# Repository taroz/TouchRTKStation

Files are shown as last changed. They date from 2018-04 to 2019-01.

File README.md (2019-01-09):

# TouchRTKStation
日本語で説明は[**こちら**](https://qiita.com/taroz/items/fe5373848153430bf19d)

## Introduction
- TouchRTKStation is an open-source single-frequency RTK-GNSS rover and base station project
- Single frequency GNSS antenna/receiver+ Raspberry Pi + Touchscreen + RTKLIB + Case
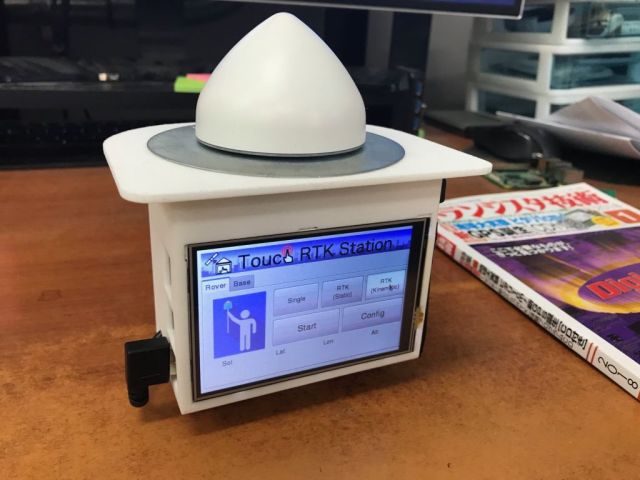
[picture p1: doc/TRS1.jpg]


## Functions
### Rover station
- GNSS raw data and RTK-GNSS solutions can be stored in USB memory
- Single point positioning, Kinematic RTK-GNSS, and Static RTK-GNSS are supported

### Base station
- GNSS raw data can be stored in USB memory
- TCP server, Ntrip Server, and Ntrip caster functions can be used to transmit GNSS data to a rover station
- Wireless communication devices such as ZigBee can be used

## Features
- Using [RTKLIB](https://github.com/tomojitakasu/RTKLIB) for processing GNSS data
- This project is inspired by [RTKLIB_Touchscreen_GUI](https://github.com/Francklin2/RTKLIB_Touchscreen_GUI)
- To compared with [RTKLIB_Touchscreen_GUI](https://github.com/Francklin2/RTKLIB_Touchscreen_GUI)
  - More smaller (5 inch => 4 inch)
  - Simple implementation using RTKLIB applications (rtkrcv and str2str)
  - GUI is developed by PyQT and easily customizable

## How to assemble
### Parts
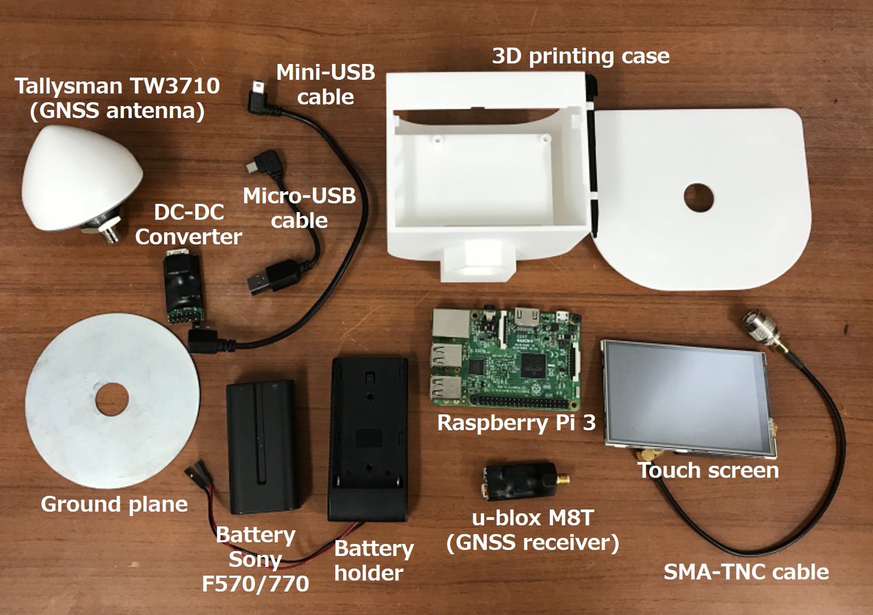
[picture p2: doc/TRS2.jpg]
<p>

- **Case:**  Create using 3D printer (STL data is [here](https://github.com/taroz/TouchRTKStation/blob/master/3D))
  - Or buy from [Shapeways](https://www.shapeways.com/shops/tarosuzuki)
- **GNSS receiver:** u-blox M8T [CSG shop](http://www.csgshop.com/product.php?id_product=205)
- **Mini-USB cable:**
- **GNSS antenna:** Tallysman TW3710 or TW3740 (GPS+GLO+BDS L1) [Digi-Key(TW3710)](https://www.digikey.com/products/en?keywords=tw3710) or  [Digi-Key(TW3710)](https://www.digikey.com/products/en?keywords=tw3740)  
- **Raspberry Pi 3:**
- **micro SD card:**
- **TNC(P)-SMA(J) connector:**
- **SMA(P)-SMA(P) cable:**
- **4inch Display:** Waveshare 4inch_RPi_LCD [Waveshare](https://www.waveshare.com/4inch-rpi-lcd-a.htm)
- **DC-DC converter:** 7.4V to 5V [Strawberry Linux](https://strawberry-linux.com/catalog/items?code=18697), [Amazon](https://www.amazon.com/DZS-Elec-Converter-Regulator-Charging/dp/B07121W7Q4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)
- **micro-USB cable:**
- **Battery holder:** Lilliput Battery Plate for Sony Battery F-970 [eBay](https://www.ebay.com/itm/LILLIPUT-Battery-Adapter-Base-Plate-F970-for-Sony-VX2100E-HVR-V1C-F330-/371421670220), [Amazon](https://www.amazon.com/Battery-Adapter-VX2100E-Lilliput-Accessory/dp/B009SJIG0K)
- **Battery:** Sony NP-F550/F570 (2900mAh) or NP-F750/F770 (5000mAh) [Amazon](https://www.amazon.com/dp/B07DC5RYPM/ref=cm_sw_em_r_mt_dp_U_qOHnCbFWY47XD)
- **5/8 inch nut:**
- **Ground plane:**

## Setup (Hardware)
- Modify the battery holder
- Open and directly connect to the DC-DC converter  
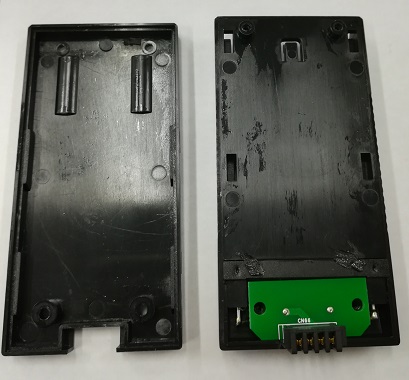
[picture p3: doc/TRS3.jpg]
<p> 
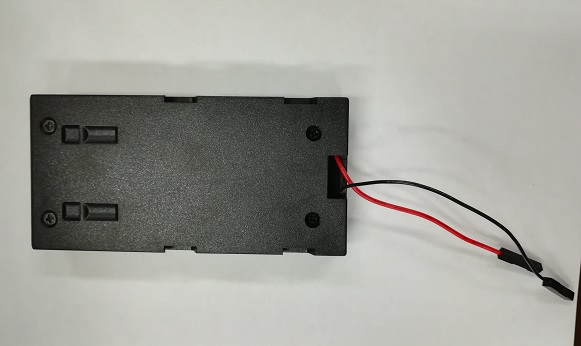
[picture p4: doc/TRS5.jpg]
<p>  

- Mount the battery holder to the main case  
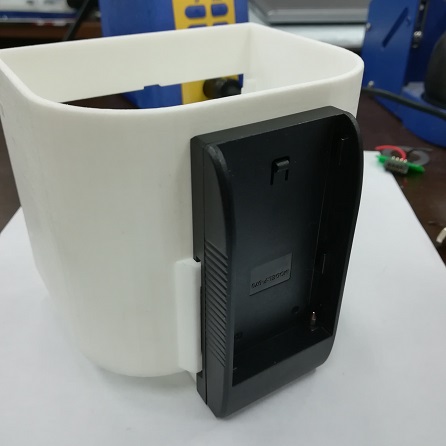
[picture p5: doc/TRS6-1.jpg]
<p>  

- Mount Raspberry Pi to the main case  
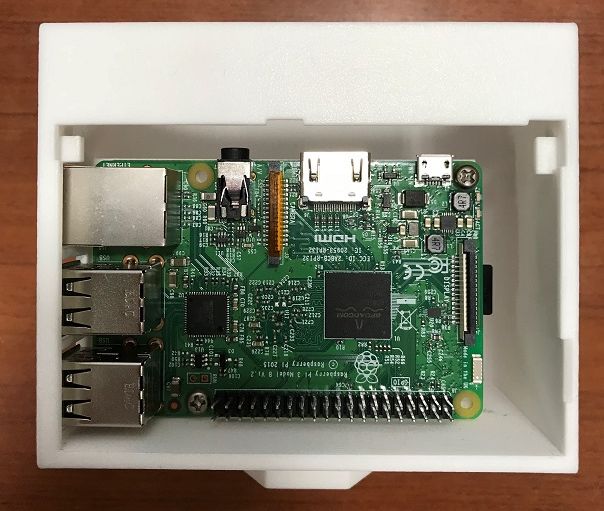
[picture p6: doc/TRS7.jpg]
<p>  

- Mount the Tallysman GNSS antenna to the top plate  
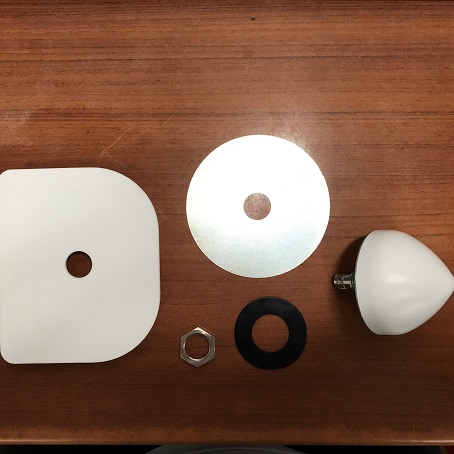
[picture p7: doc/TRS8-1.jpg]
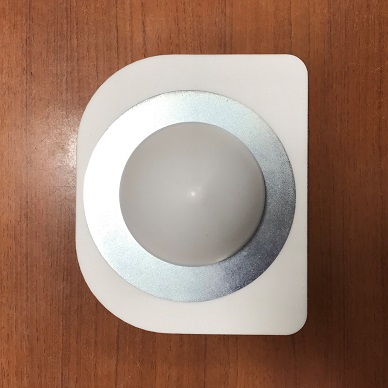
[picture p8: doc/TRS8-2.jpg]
 <p>  

- Connect the GNSS antenna cable to the GNSS receiver.
- Connect the USB cables  
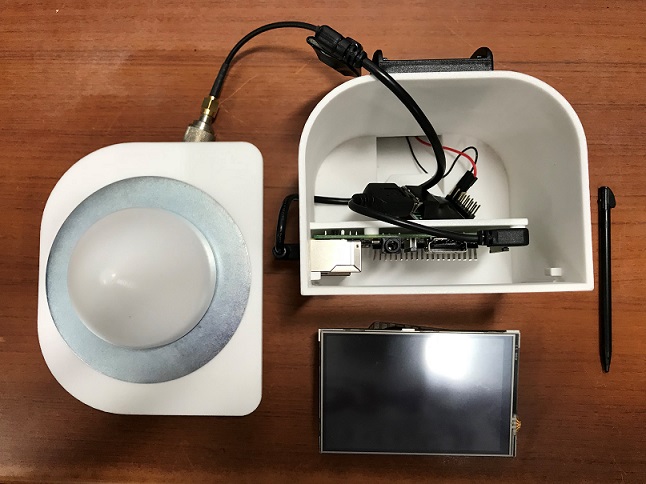
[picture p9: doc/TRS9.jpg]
<p>  

- Mount the touch screen and put the top plate to the main case  
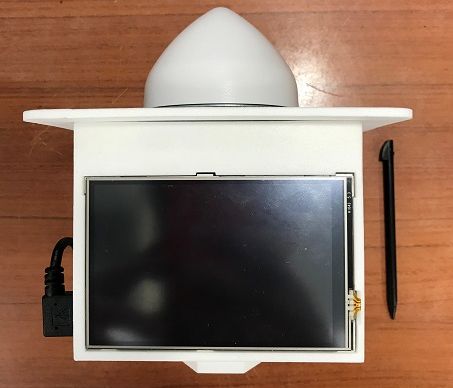
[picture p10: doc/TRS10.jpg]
<p>  

## Setup (Software)
### Install Raspbian
- See [here](https://www.raspberrypi.org/documentation/installation/installing-images/)

### Install TouchRTKStation
1. Connect the Raspberry Pi to the internet.
2. Download the TouchRTKStation  
    `$ cd /home/pi/`  
    `$ git clone https://github.com/taroz/TouchRTKStation.git`
3. Connect the 4inch touch screen to the Raspberry Pi. Run Install.sh  
    `$ cd /home/pi/TouchRTKStation/install`  
    `$ sudo sh Install.sh`
4. 4inch touch screen is enabled. If you want to return back to HDMI output,   
    `$ cd LCD-show`  
    `./LCD-hdmi`
5. Run TouchRTKStation  
    `$ sudo python3 /home/pi/TouchRTKStation/TouchRTKStation.py`
6. If you want to quit the TouchRTKStation, use Alt+F4
7. If you want to automatically start the TouchRTKStation  
    `$ cd /home/pi/TouchRTKStation/install`  
    `$ sudo sh Autostart.sh`

## How to use
1. Insert a USB memory to the Raspberry Pi. GNSS raw data (.ubx file) is stored in the USB memory. In the rover mode, positioning results (.pos file) are also stored. If there is no USB memory, GNSS data are stored in the home directory of the Raspberry Pi.
2. To connect NTRIP caster or NTRIP server in the rover mode, or to connect a rover in the base mode, a network connection via WiFI is needed. The wireless communication device such as ZigBee dongle, which can be recognize as USB serial port, is also can be used.

### Rover mode
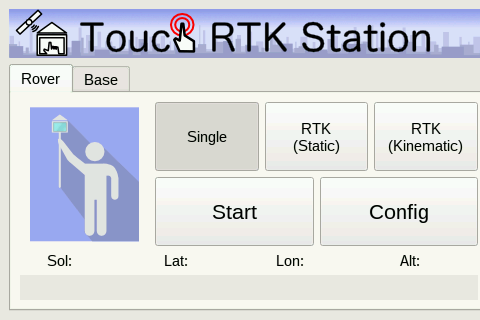
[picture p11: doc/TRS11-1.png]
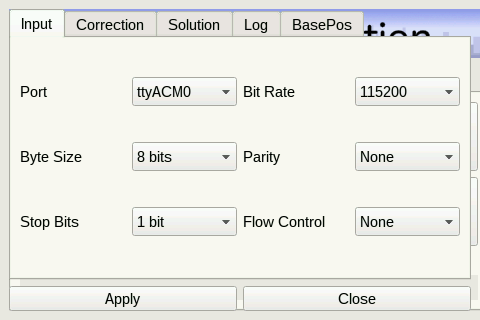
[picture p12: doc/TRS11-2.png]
 

1. Select “**Rover**” tab. Select “**Single**”，”**RTK(Static)**”, or “**RTK(Kinematic)**”
2. Push “**Config**”.  For RTK-GNSS, setup the input stream information in the “**Correction1**” tab. If ZigBee or any wireless communication device, which are recognized as USB serial port, is used to receive the GNSS data, setup the input stream information in “**Correction2**” tab. In the “**BasePos**” tab, input the base sanitation position．
3. Push “**Start**”.  Positioning results will be shown after GNSS ephemeris data are decoded.
4. Push “**Stop**”. GNSS Raw data and positioning result are stored in the USB memory.

### Base mode
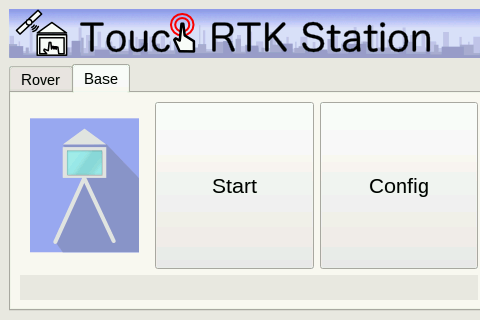
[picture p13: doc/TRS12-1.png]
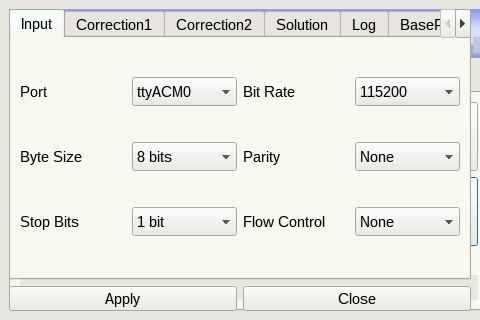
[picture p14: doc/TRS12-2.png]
 

1. Select “**Base**” tab.
2. Push “**Config**”.  To broadcast GNSS correction data, setup a output stream information in the “**Output1**” tab. If ZigBee or any wireless communication device, which are recognized as USB serial port, is used to transmit the GNSS data, setup the output stream information in “**Output2**” tab. If you want to convert the UBX format to the RTCM format, input the base station position in "**BasePos**” tab.
3. Push “**Start**”. GNSS data will be stored or broadcasted.
4. Push “**Stop**”. GNSS Raw data are stored in the USB memory.

### Configure default settings

Modify L26 to L97 in **"TouchRTKStation.py"**
```python
# ublox command file for Base/Rover mode
ubxcmd = dirtrs+'/conf/ubx_m8t_bds_raw_1hz.cmd'

# Default Base position configuration
basepos_type = (['LLH','RTCM']) # for Rover
basepos_itype = 1 # for Rover
basepos_lat = '35.0'
basepos_lon = '139.0'
basepos_hgt = '50.0'

# Default Input stream configration
input_iport= 2         # ttyACM0
input_ibitrate = 9     # 115200 bps
input_ibytesize = 1    # 8 bit
input_iparity = 0      # None
input_istopbits = 0    # 1 bit
input_iflowcontrol = 0 # None

# Default Correction stream configration
corr_flag = False
corr_type = (['NTRIP Client','TCP Client'])
corr_itype = 0
corr_format = (['RTCM2','RTCM3','BINEX','UBX'])
corr_iformat = 1
corr_user = 'user'
corr_addr = 'test.net'
corr_port = '2101'
corr_pw = 'password'
corr_mp = 'RTCM'

# Default Correction(Serial) stream configration
corr2_flag = False
corr2_format = (['RTCM2','RTCM3','BINEX','UBX'])
corr2_iformat = 3
corr2_iport= 4         # ttyUSB0
corr2_ibitrate = 9     # 115200 bps
corr2_ibytesize = 1    # 8 bit
corr2_iparity = 0      # None
corr2_istopbits = 0    # 1 bit
corr2_iflowcontrol = 0 # None

# Default Log/Solution stream configration
log_flag = True
sol_flag = True
dir = glob.glob('/media/*/*/') # Find USB memory
if len(dir)==0:
    dir = [dirtrs+'/']
sol_filename = dir[0]+'%Y-%m%d-%h%M%S.pos'
log_filename = dir[0]+'%Y-%m%d-%h%M%S.ubx'

# Default Output stream configration
output_flag = False
output_type=(['TCP Server','NTRIP Server','NTRIP Caster'])
output_itype = 0    # TCP Server
output_format = (['UBX','RTCM3'])
output_iformat = 0  # UBX
output_user = 'user'
output_addr = 'test.net'
output_port = '2101'
output_pw = 'password'
output_mp = 'TRS'

# Default Output(Serial) stream configration
output2_flag = False
output2_format = (['UBX','RTCM3'])
output2_iformat = 0      # UBX
output2_iport= 4         # ttyUSB0
output2_ibitrate = 9     # 115200 bps
output2_ibytesize = 1    # 8 bit
output2_iparity = 0      # None
output2_istopbits = 0    # 1 bit
output2_iflowcontrol = 0 # None
```

### Configure positioning settings

Modify the **"xxxx.conf"**  file of RTKLIB.
Configuration files are in the following directory

`$ cd /home/pi/TouchRTKStation/conf/`
- **Single point positioning:** `/home/pi/TouchRTKStation/conf/single.conf`
- **RTK-GNSS (Kinematic):** `/home/pi/TouchRTKStation/conf/kinematic.conf`
- **RTK-GNSS(Static):** `/home/pi/TouchRTKStation/conf/static.conf`

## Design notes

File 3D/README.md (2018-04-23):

# TouchRTKStation 3Dプリンタ用データ
* [TouchRTKStation_main.STL](./TouchRTKStation_main.STL): ケース本体
* [TouchRTKStation_main.STL](./TouchRTKStation_top.STL): フタ

* 次のshopに出品しているので，下記から直接購入することもできます
  * [DMM.Make](https://make.dmm.com/shop/130606/)
  * [Shapeways](https://www.shapeways.com/shops/tarosuzuki)  

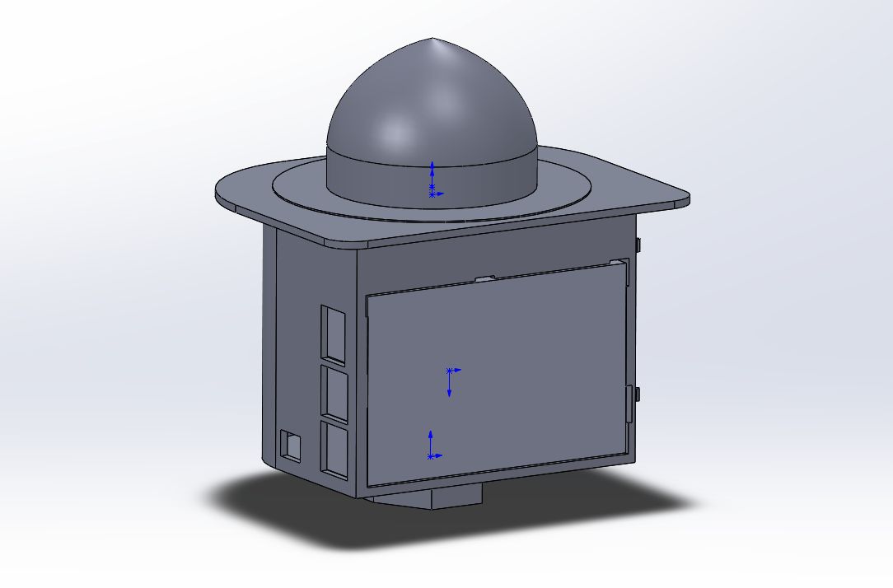
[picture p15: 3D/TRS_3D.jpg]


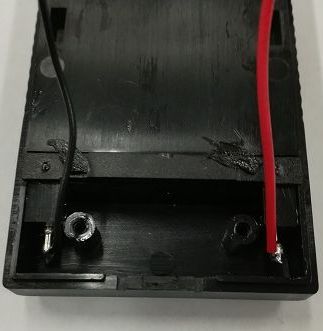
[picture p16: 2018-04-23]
doc/TRS4-2.jpg

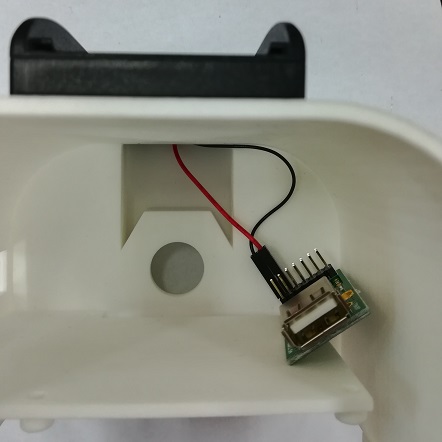
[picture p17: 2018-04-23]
doc/TRS6-2.jpg

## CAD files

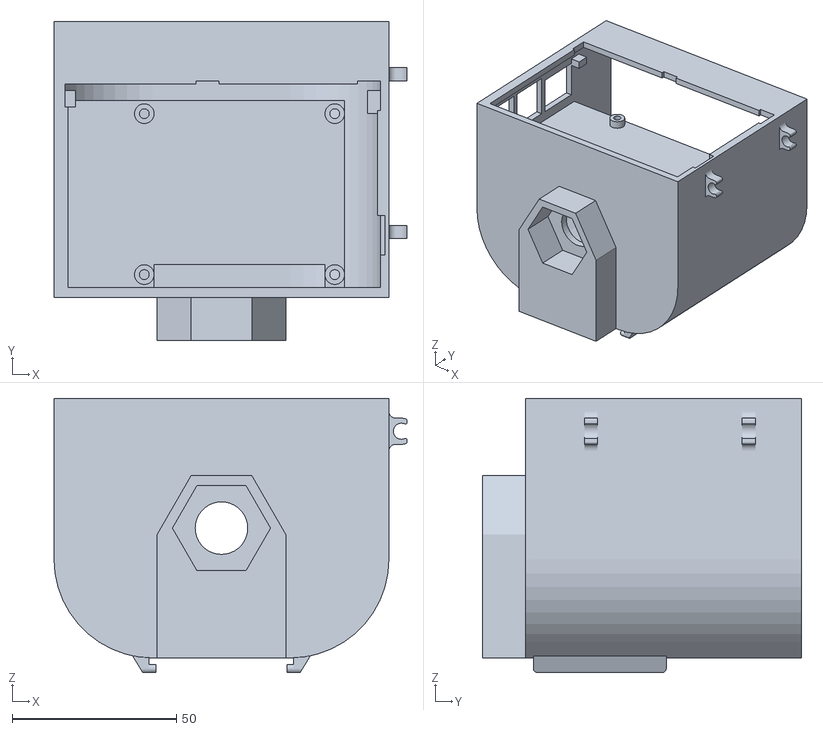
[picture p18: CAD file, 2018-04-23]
3D/TouchRTKStation_main.STL
107.5 x 97.0 x 83.5

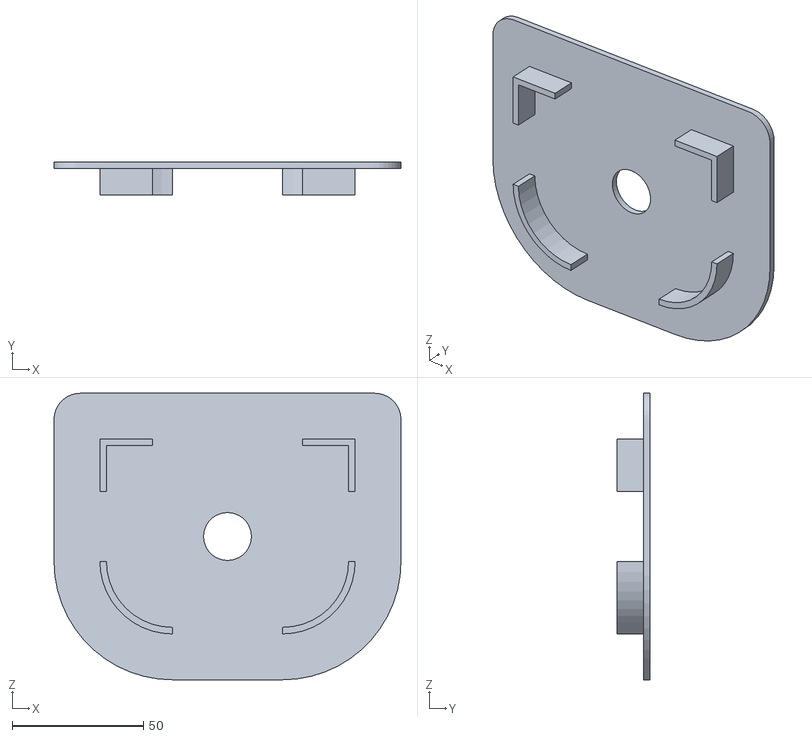
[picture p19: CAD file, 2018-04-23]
3D/TouchRTKStation_top.STL
132.0 x 12.5 x 109.0

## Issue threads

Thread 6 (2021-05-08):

Rover mode, .pos file empty and no Sol: Lat: Lon: Alt: data

Church1182, 2021-05-08:
I've been working on adding a couple extra tabs to the program and ran into issue where I no longer get any solution data displayed in rover mode and the .pos file is empty save for the headers. No actual data.  The .ubx file saves and seems to be fine.
I'm using a pi3 B+ and I started with the [NEO-M8T from gnss.store](https://www.gnss.store/gnss-gps-modules/45-ublox-neo-m8t-time-raw-receiver-board-with-sma-rtk-ready.html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) and the unmodified program. In my final build I'm using the [waveshare HAT with the same ublox NEO-M8T chip](https://www.waveshare.com/neo-m8t-gnss-timing-hat.htm). At first I though it was just a config issue, but I've triple checked that the config is the same on all my M8T's and was working fine before.

I have tried using the usb connected board from gnss.store and the unmodified program and still nothing.

Any ideas whats going on, or what to look at to figure it out?

The extra tab I added so far is just a tab with 3 buttons, Exit, Reboot, Shutdown.

geofis, 2021-05-08:
Hello @Church1182

I think you can perform a post-processing solution (PPK) to check if the receiver is working fine. To do so, convert the raw observations from the UBX file to RINEX format (using `convbin`) from both base and rover (I assume the receiver is configured to record raw observations).

If you don't have a base station on your own, you may be receiving corrections from a nearby base station, which hopefully stores observations in a server (i.e. FTP). Locate the file comprising the time span of the UBX file of the rover and convert them to RINEX format (`convbin` again).

With the raw observations from the base and the rover, you could try `rnx2rtkp` to perform a PPK solution. If you get solutions (Q=2 float or Q=1 fix), the receiver is working fine. If not, then you may need to check the configuration of the receiver, using u-center. You can also double-check the `.cmd` files of the repo to check if they are configured fine.

Good luck.

Church1182, 2021-05-09:
Thanks for the advice, I will give that a try. I do have another unit setup at my shop that is running in base mode and there is an NGS NOAA CORS site 18.46 km from my shop. I ran three 24 hour collections a week apart and processed them with data from the CORS site to get 3 fixes that were the same to the 8th decimal. I was happy with that.

I noticed that in Tho my on my Pi when I end the program the shell read out looks like this;
...
rtkrcv>
solution
rtkrcv>
malloc(): unsorted double linked list corrupted

From what I have found so far that appears to be a gcc related issue. Something with RTKLIB?

geofis, 2021-05-09:
You're welcome.

I agree with you that it may be a gcc related issue. I am not familiar with the compilation process, but I faced a similar issue while trying to install RTKLIB alongside TouchRTKStation. I found that the new version of RTKLIB changed the main path for the apps, so the developer added a new directory inside the app directory. To solve this, before the installation, I added multiple symlinks inside the app directory pointing to the directories of the apps, such as:

```
ln -s /home/pi/RTKLIB/app/consapp/* /home/pi/RTKLIB/app/
```

You may find this change on line 31 of the `install/Install.sh` file of my forked repo [here](https://github.com/geofis/TouchRTKStation). In this file, you may also see that I use the forked repo [demo5](https://github.com/rtklibexplorer/RTKLIB), instead of the RTKLIB itself.

Church1182, 2021-05-09:
I opted for editing the python file and finding the two lines where the program was trying to call rtkrcv or str2str and added the /app/ into the path. It seems to work fine, I just haven't figured out why it stopped displaying the information on the rover tab while it's running and populating the .pos file. The .ubx file is fine so far as I can tell.
I've made my own fork to add the changes I've made.

Church1182, 2021-05-12:
I went out yesterday and collected data with my rover and about 30 seconds in I got a Float and then Fix solution with position data. At this point I can only assume my previous instances were a lack of sufficient satellite signal to get a good fix. There does not seem to be an issue and I will close this.

Closed 2021-05-12.
